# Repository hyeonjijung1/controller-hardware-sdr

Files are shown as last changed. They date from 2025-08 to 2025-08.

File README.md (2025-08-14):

# Subsystem C: SDR Controller Hardware  
_Led a 3-person team and delivered the Technical Review Presentation as Team Lead_

> **TL;DR:**  
> Modular SDR controller featuring custom 2-layer PCB, AVR firmware, and Si5351A frequency generation. Achieves ±1 kHz LO accuracy and 0.5° I/Q phase error—fully validated with oscilloscope and logic analyzer. Built, debugged, and documented from schematic to firmware to hardware bring-up.

**Technologies:**  Altium Designer · PCB Design · Embedded C (AVR) · ATmega324PB · Si5351A (I²C) · UART (CAT Protocol) · I²C LCD Interface · Bash & Python Scripting · Oscilloscope Validation · Git






A high-performance hardware controller built for **Software-Defined Radio (SDR)** systems, integrating **Local Oscillator (LO) generation**, **TX/RX control**, and a **user interface** to support modular, high-accuracy signal processing.

| 3D PCB Render | Assembled PCB |
|:---:|:---:|
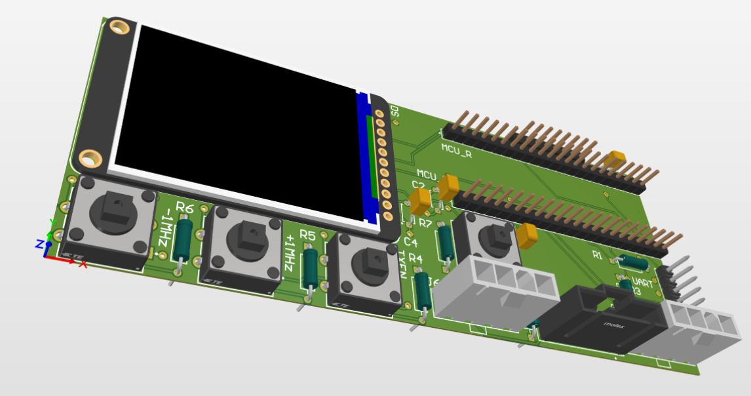
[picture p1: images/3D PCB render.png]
3D PCB Render
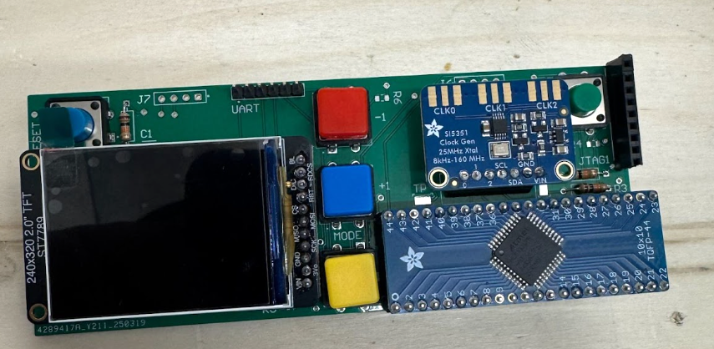
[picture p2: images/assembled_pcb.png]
Assembled PCB
|  |  |

<p align="center"><b>Figure:</b> 3D PCB render (left) and fully assembled SDR controller board (right).</p>

---
## Table of Contents

- [Project Summary](#project-summary)
- [Key Design Decisions](#key-design-decisions) 
- [Key Contributions & Impact](#key-contributions--impact)  
- [Getting Started](#getting-started)
- [Repo Structure](#repo-structure) 
- [Architecture](#architecture)  
- [PCB Design & Schematics](#pcb-design--schematics)
- [Challenges & Lessons Learned](#challenges--lessons-learned)
- [Validation & Test Results](#validation--test-results)
- [How to Replicate / Order PCB](#how-to-replicate--order-pcb)
- [Supporting Materials](#supporting-materials)  
- [What We Learned](#what-we-learned)  
- [Contact & Contributors](#contact--contributors)

---

## Project Summary

This repository contains the design and firmware for **Subsystem C** of a larger SDR transceiver. It handles:

- Generating a stable, precision **10 MHz LO** for quadrature mixers  
- **TX/RX gating** via an active-low enable signal  
- A **front-panel UI** (push-buttons + 16×2 I²C LCD) for frequency tuning and mode switching  
- **Automated hardware and firmware validation** using Bash and Python test scripts  
- Full compliance with the **Interface Control Document (ICD)**  

**Platform:** Custom 2-layer PCB (Altium Designer)  
**MCU:** ATmega324PB  
**Clock Generator:** Si5351A (I²C-programmable)  
**UI:** Push buttons + 16×2 character I²C LCD  
**Validation Tools:** Oscilloscope, Function Generator, Bash/Python automation scripts

---

## Key Design Decisions

Our design focused on intuitive user experience, reliable performance, and seamless integration with modular SDR systems.

- **Intuitive User Interface:**  
  Implemented three tactile push-buttons and a 16×2 I²C LCD on the front panel, enabling all key SDR controls—frequency tuning, TX/RX switching, and mode selection—without needing a PC or serial commands. This focus on usability makes the controller accessible to both technical and non-technical users.

- **Compact, Modular PCB Layout:**  
  Designed as a 128 × 51 mm daughtercard to fit within the overall SDR enclosure, supporting easy integration and replacement.

- **RF/Digital Trace Isolation:**  
  Separated RF signal paths from digital control sections to reduce noise and ensure clean LO generation.

- **Component Selection for Robustness:**  
  Chose the ATmega324PB microcontroller for ample I/O and the Si5351A for stable, programmable LO generation.

- **Testability and Validation:**  
  Included accessible test points and supported automated validation with Python/Bash scripts and oscilloscope measurements.

---
  
## Key Contributions & Impact

- **±1 kHz LO stability** (0.01% error) and **90° I/Q phase accuracy** under lab conditions  
- **50% faster** bring-up cycles using automated Python/bash test scripts  
- Designed & PCB-routed a **compact 128 × 51 mm** daughtercard, isolating RF traces from digital noise  
- Authored the **Technical Design Document**, detailing architecture, component trade-offs, and test plans  
- Programmed embedded C for **Si5351A (I²C)**, **UART (CAT protocol)**, and **LCD control**  
- **Led a 3-member team** end-to-end: schematic → PCB → firmware → integration  
- **Presented** the M2 Technical Review, covering timing closure, signal integrity, and ICD alignment  

---

## Getting Started

```bash
# Clone the Subsystem C repo
git clone https://github.com/hyeonjijung1/controller-hardware-sdr
cd controller-hardware-sdr

# Build firmware
make all

# Flash the ATmega324PB (via AVRDUDE or your preferred tool)
make flash
```
Once programmed, power the mainboard at 12 VDC, attach your UI module to J7/J8, and observe the LCD. Use the push-buttons to tune frequency and toggle TX/RX.

---

## 📁 Repo Structure

```bash
.
├── docs/                     # Project documents & design slides
│   ├── ECE295_Team4C_Technical_Design_Doc.pdf
│   ├── M2_design_review_slides.pdf
│   └── Team4C_OP2_Slides.pdf
├── firmware/                 # Embedded C source & build files
│   ├── include/              # Header files
│   │   ├── Si5351.h
│   │   └── twi.h
│   ├── src/                  # Source files
│   │   ├── main.c
│   │   ├── Si5351.c
│   │   └── twi.c
│   └── Makefile
├── hardware/                 # Altium project files
│   ├── Controller_Hardware_SDR_sch.SchDoc
│   └── Controller_Hardware_SDR.PcbDoc
├── images/                   # Visuals for documentation
│   ├── 3D PCB render.png
│   ├── assembled_pcb.png
│   └── Output LO waveforms demonstrating correct phase and amplitude.png
├── scripts/                  # Test & automation scripts
│   ├── cat_test.py
│   ├── lo_auto_validation.py
│   └── test_lo_accuracy.sh
├── LICENSE
└── README.md

```

---

## Architecture

Block Diagram
*Figure 1. Subsystem C SDR Block Diagram.*

---

## PCB Design & Schematics 

### PCB Design 

| 3D PCB Render | Top View | Bottom View |
|:---:|:---:|:---:|
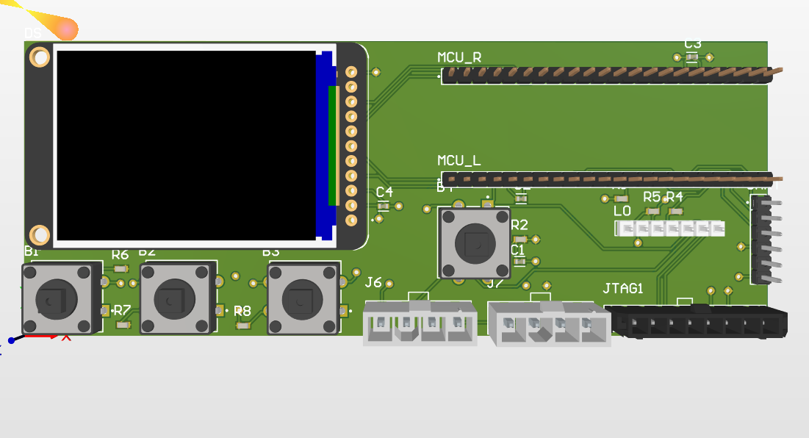
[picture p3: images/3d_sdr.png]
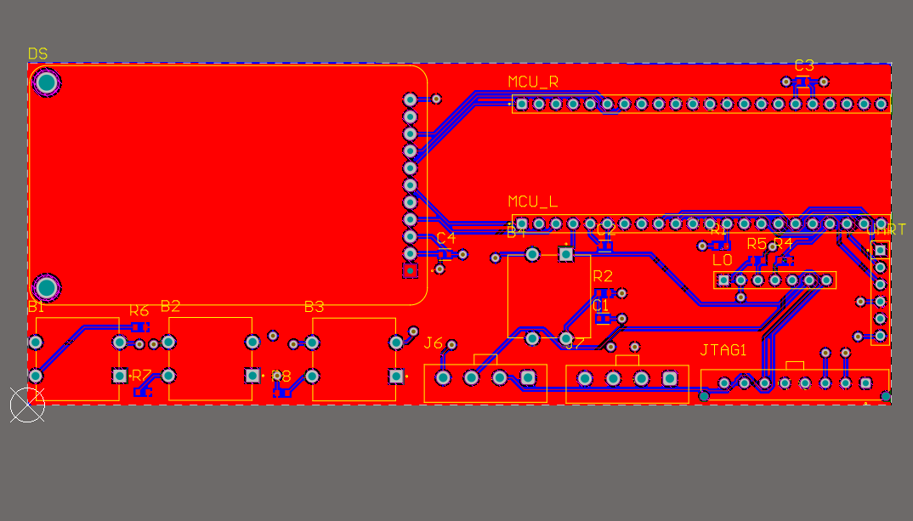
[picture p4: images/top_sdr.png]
PCB Top
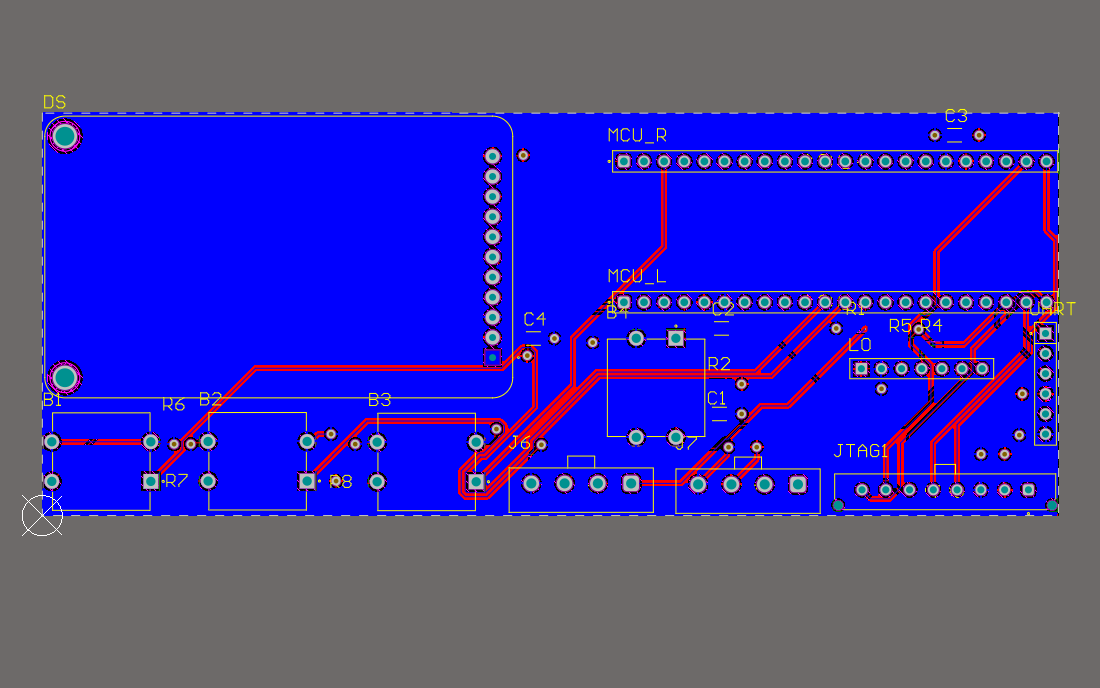
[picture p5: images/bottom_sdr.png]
PCB Bottom
|  |  |  |

<p align="center"><b>Figure:</b> 3D render, top, and bottom views of the SDR controller PCB (Altium Designer).</p>

### Schematics 

| Original Schematic | Final Schematic |
|:---:|:---:|
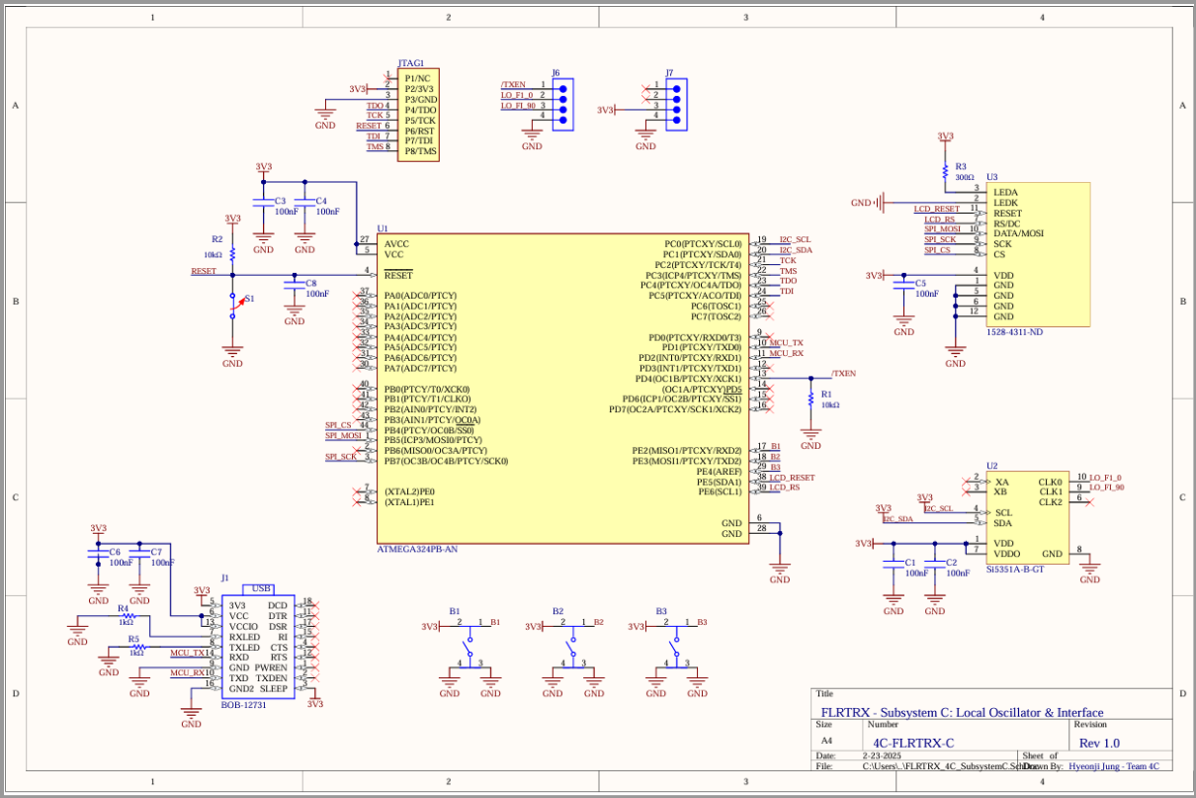
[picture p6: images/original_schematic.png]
Original Schematic
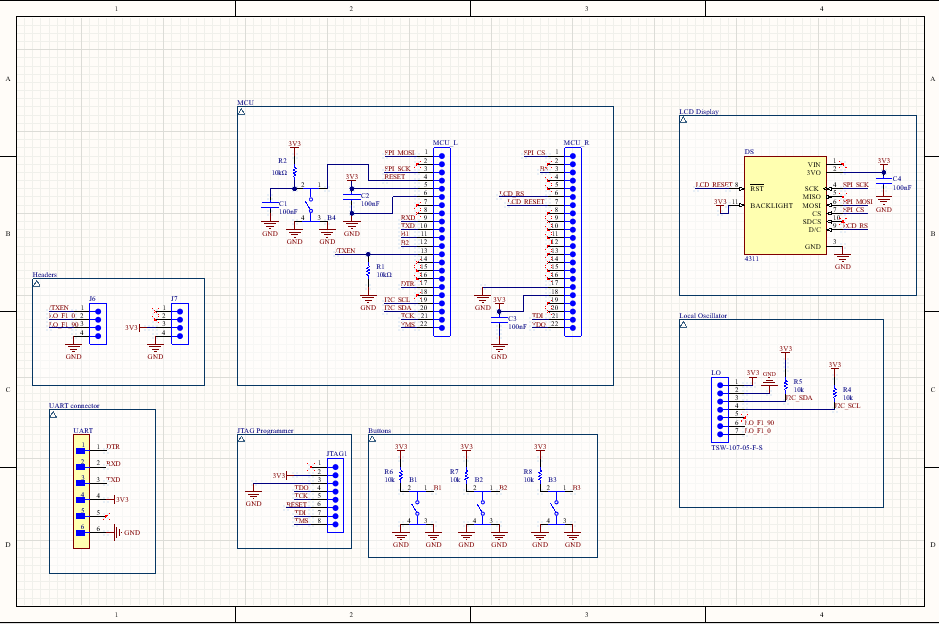
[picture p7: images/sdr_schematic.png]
schematic
|  |  |
<p align="center"><b>Figure:</b> Schematic in first iteration (left) and finalized Altium Schematic (right).</p>

---
## Challenges & Lessons Learned

Real hardware design is never plug-and-play—here’s what we faced and how we solved it:

- **Assembly Sequence Error:**  
  Our initial assembly failed because we soldered through-hole components before the surface-mount parts, preventing reflow soldering. We corrected this by assembling surface-mount components first on our next build.

- **Microcontroller Orientation Mistake:**  
  The ATmega324PB was mounted in the wrong orientation, misaligning the pinout and breaking the logic chain. To recover, we used jumper wires with male-to-female headers to manually connect the MCU to the correct pads—an inelegant but functional patch.

| Wrong MCU Orientation (Design/Assembly) | Corrected with Jumper Wires |
|:---:|:---:|
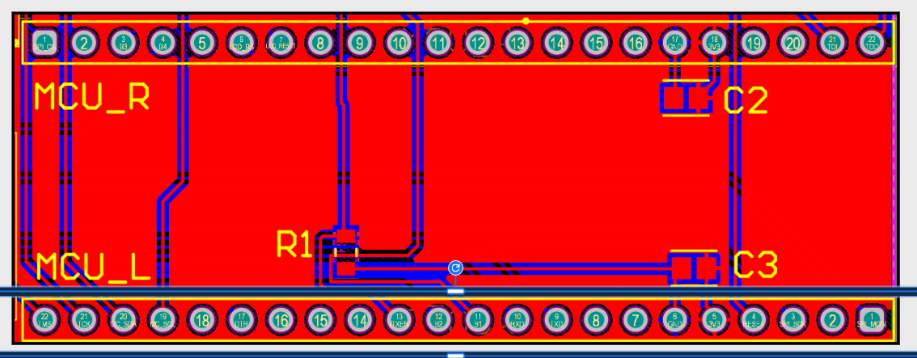
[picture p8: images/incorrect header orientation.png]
MCU wrong orientation in Altium PCB
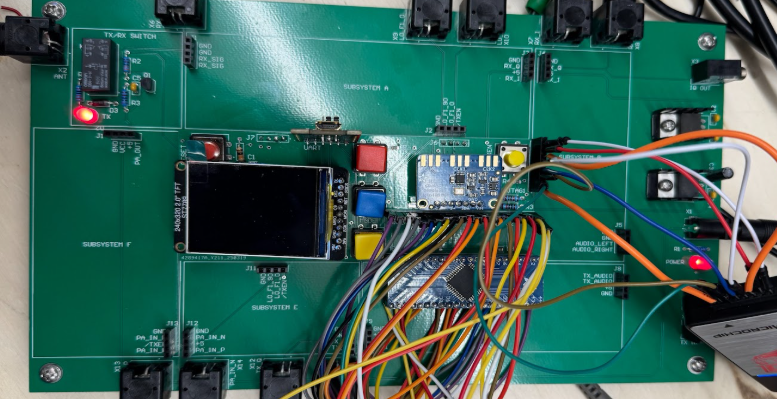
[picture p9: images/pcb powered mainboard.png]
Jumper wires patching MCU orientation
|  |  |
| <sub><b>Figure:</b> PCB as assembled with incorrect MCU orientation;logic chain broken.</sub> | <sub><b>Figure:</b> Functional patch using jumper wires to restore connections after the assembly error.</sub> |

- **Button Instability:**  
  Some push-buttons failed on the PCB despite working on breadboard. The reset button, a different type, worked reliably, pointing to hardware quality issues.

- **TXEN Signal Glitch:**  
  The TXEN (Transmit Enable) signal toggled incorrectly due to a debounce/logic error in firmware. Despite several software fixes, the issue persisted and requires further debugging.

- **UART Communication Issues:**  
  Serial comms established, but the MCU sometimes sent incorrect/blank responses. Switching to interrupt-based UART caused repeated interrupts, locking the radio in computer-control mode—an unresolved but valuable learning experience.

**Key Takeaway:**  
Every challenge forced us to dig deeper, learn new debugging skills, and improvise fixes to keep the project moving forward; real hardware design in a nutshell.

---

## Validation & Test Results

| Test | Target / Spec | Result / Measured | Status |
|---|---|---|---|
| LO Frequency Accuracy | ±1 kHz @ 10 MHz | ±1 kHz (oscilloscope) | ✔️ |
| I/Q Phase Error | <1° | ~0.5° (measured) | ✔️ |
| TX/RX Switching Time | <2 ms | ~1 ms (logic analyzer) | ✔️ |

Output LO Waveform (10 MHz, Oscilloscope)
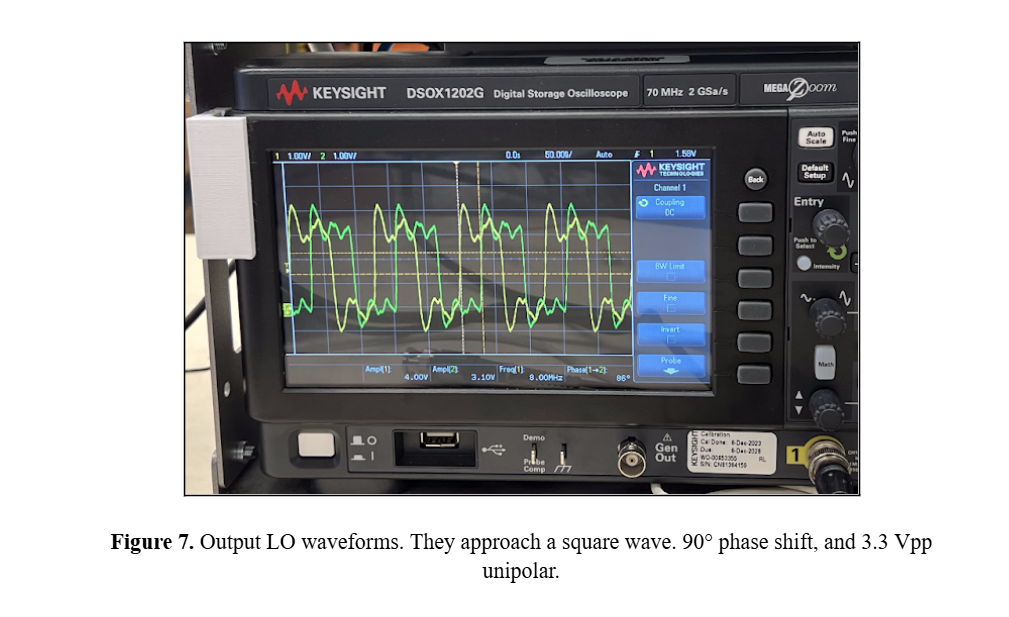
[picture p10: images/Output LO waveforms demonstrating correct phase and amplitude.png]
output


<p align="center"><b>Figure:</b> Measured LO output at 10 MHz on oscilloscope. This demonstrates stable, low-jitter signal generation by Si5351A module. Test performed post-assembly.</p>

---

## How to Replicate / Order PCB

Interested in building your own Subsystem C SDR Controller? Here’s how:

1. **Clone the repository:**
   ```bash
   git clone https://github.com/hyeonjijung1/controller-hardware-sdr
    ```
2. **Download hardware design files:**  
- Altium schematic (`.SchDoc`) and PCB (`.PcbDoc`) files are in `/hardware`
- BOM/parts list can be found in the schematic

3. **Order & fabricate PCB:**  
- Open PCB in Altium Designer, export Gerber & drill files (`File > Fabrication Outputs > Gerber Files`)
- Upload Gerbers to a PCB fab (e.g., JLCPCB, PCBWay)
- Order components from DigiKey, Mouser, or LCSC

4. **Assemble the board:**  
- Solder **surface-mount** components first (reflow oven recommended), then through-hole parts
- Double-check microcontroller orientation (refer to schematic/silkscreen)

5. **Build & flash firmware:**  
- In `/firmware`, run `make all`
- Flash ATmega324PB using AVRDUDE or compatible programmer

6. **Test your build:**  
- Power with 12 VDC, connect LCD/UI
- Validate LO output on oscilloscope
- Test push-buttons, TX/RX switching, and serial CAT protocol

> *Tip: Hardware bring-up is never plug-and-play. If you run into issues, check the “Challenges” section above for inspiration!*

---

## Supporting Materials

- [Technical Design Document (PDF)](https://drive.google.com/file/d/1lXBYHzfA1NsGeK7o8hkGUYrSS2hV9RxU/view?usp=sharing)
- [M2 Technical Presentation Slides (PDF)](https://drive.google.com/drive/u/0/folders/1bPhXOaGDvTHJFP-_4Y7tE-j0aOfVJy6w)
- [OP1 General Audience Slides (PDF)](https://drive.google.com/drive/u/0/folders/1bPhXOaGDvTHJFP-_4Y7tE-j0aOfVJy6w)
- [OP2 General Audience Slides (PDF)](https://drive.google.com/drive/u/0/folders/1bPhXOaGDvTHJFP-_4Y7tE-j0aOfVJy6w)

---

## What We Learned

- Orchestrating multi-protocol I/O (I²C + UART + GPIO) on a constrained MCU  
- Achieving tight frequency tolerance within noise and thermal drift margins  
- ICD-driven design: enforcing electrical & mechanical interface specs across teams  
- PCB routing strategies to isolate analog/RF from noisy digital sections  
- Leadership: coordinating cross-functional goals, documentation, and presentations under deadline  

---
 
## Contact & Contributors




**Diana(Hyeonji) Jung**  
Team Lead & Presenter  

**Contributors:**  
- Laura Marinescu  
- Chizaram Amobi-Oleka

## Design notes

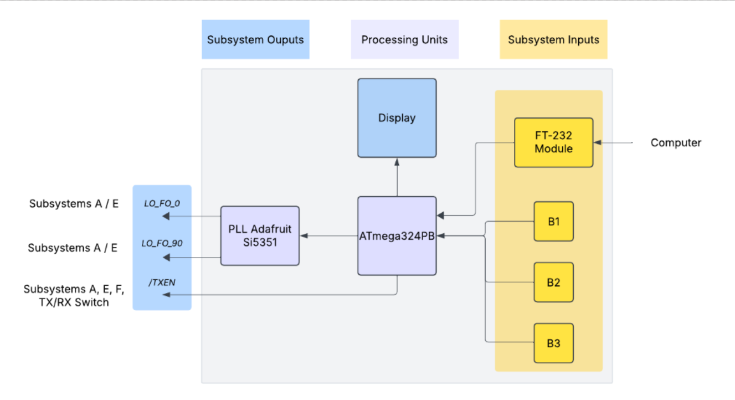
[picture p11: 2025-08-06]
images/block_diagram_sdr.png

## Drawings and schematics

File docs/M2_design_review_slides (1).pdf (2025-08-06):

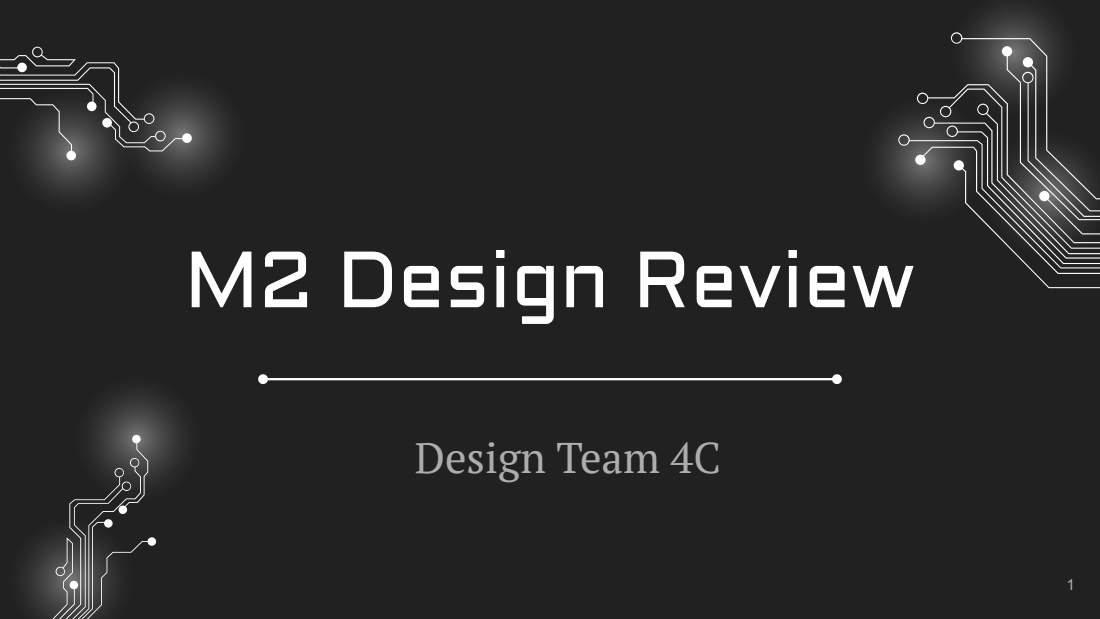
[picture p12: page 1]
M2 Design Review; Design Team 4C

# Table of contents

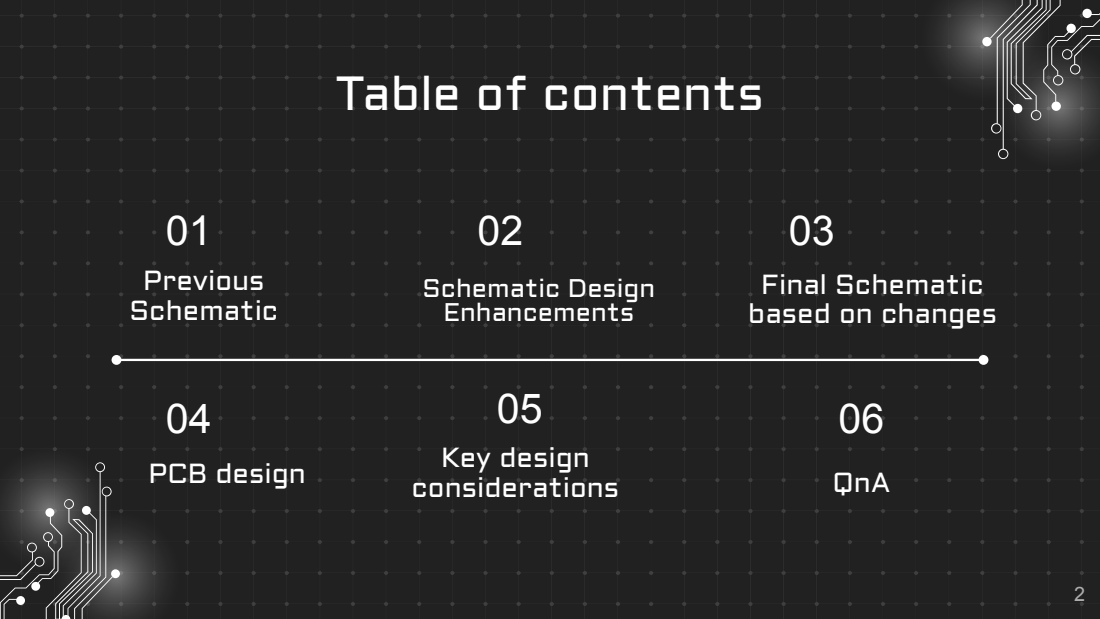
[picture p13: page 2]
Previous Schematic; Schematic Design Enhancements; PCB design; Key design; considerations; QnA

Final Schematic
based on changes

# Previous Schematic for M1

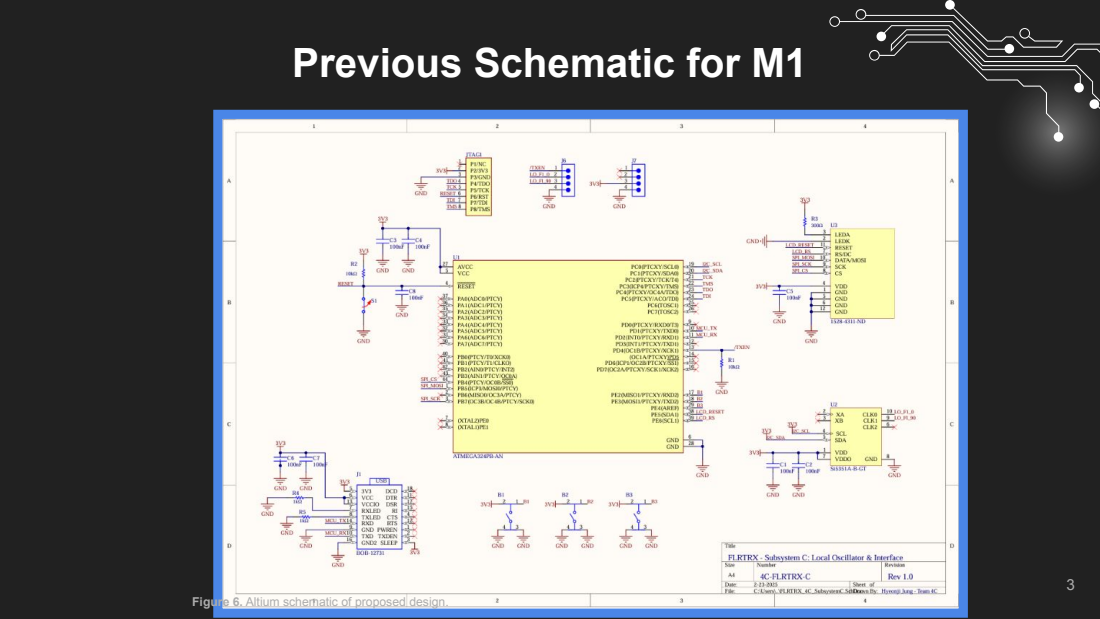
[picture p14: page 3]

Figure 6. Altium schematic of proposed design.

# Change 1. Included Boxes for Clarity

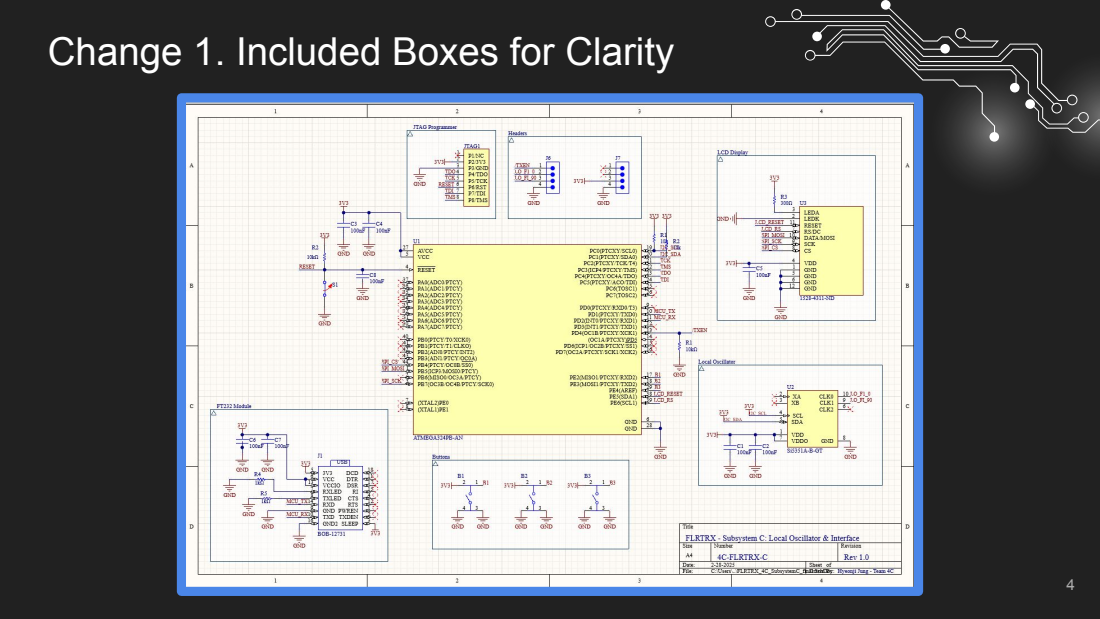
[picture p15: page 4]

Change 2. Reset switch into buttons,

# Surface mount → Through Hole components

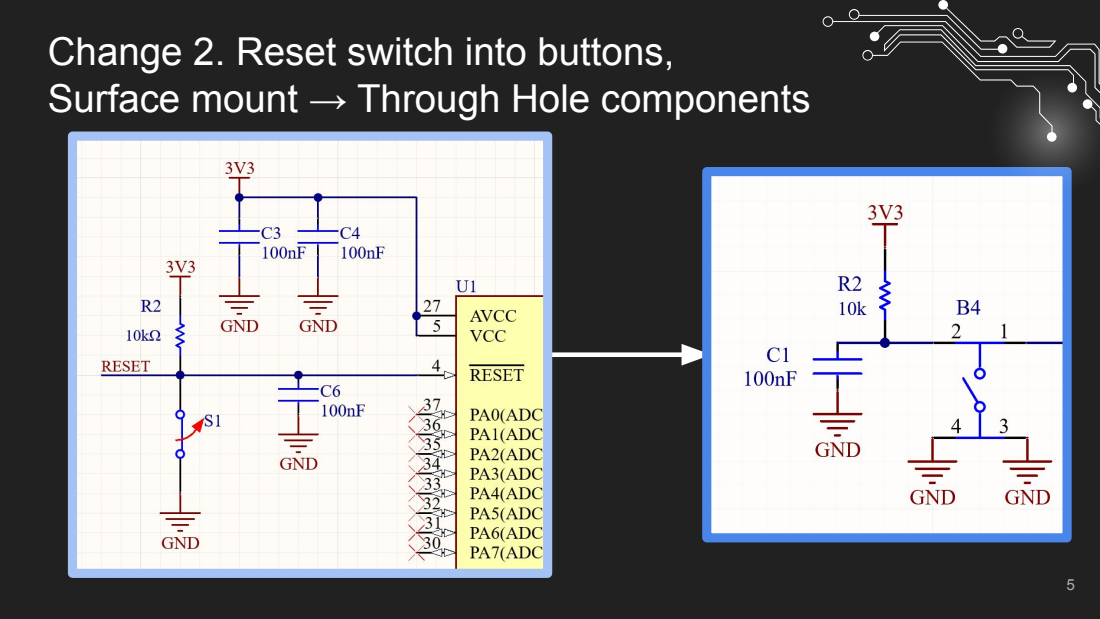
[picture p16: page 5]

# Change 3. Included Pull-up Resistors (buttons, I2C lines)

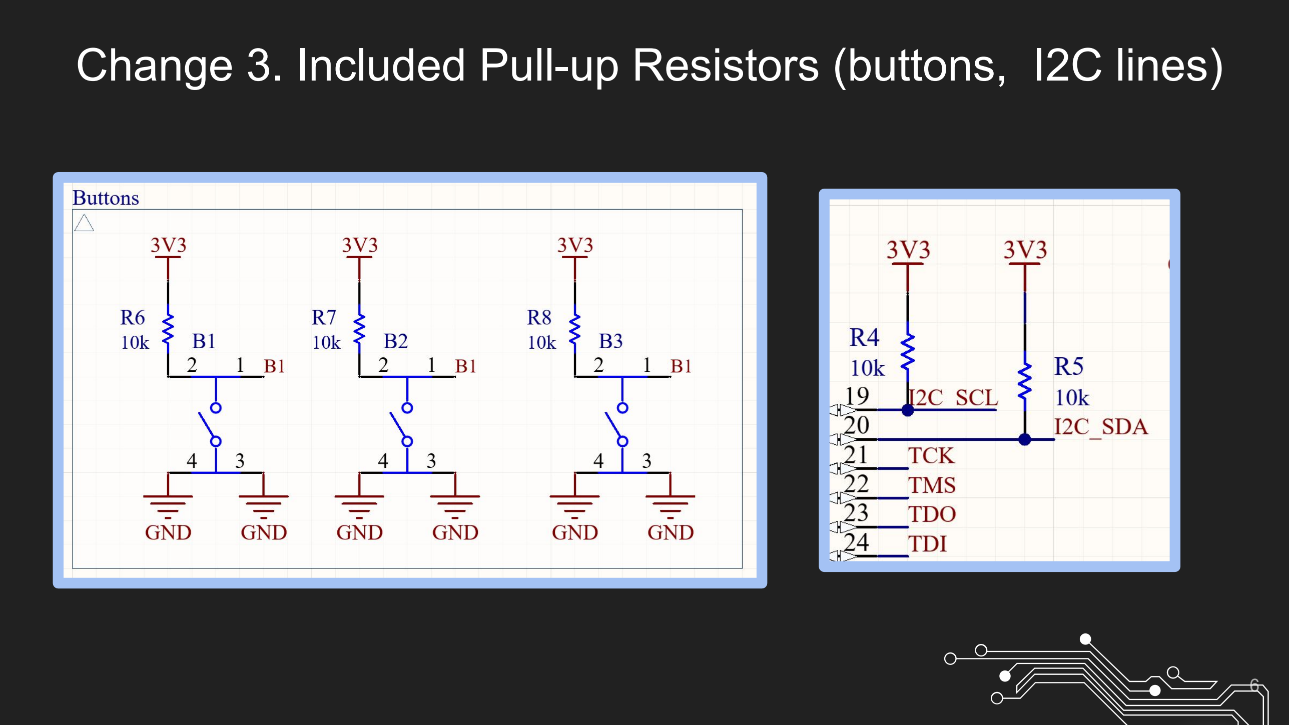
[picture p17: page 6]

# Change 4. LO module into headers

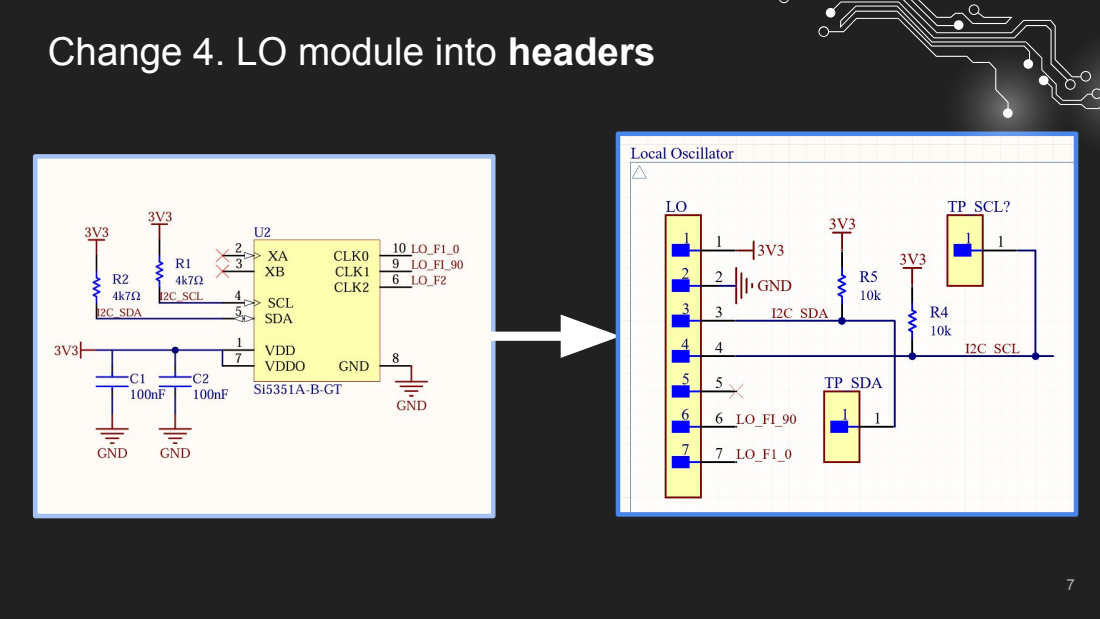
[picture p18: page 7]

# Change 5. FT232 module into headers

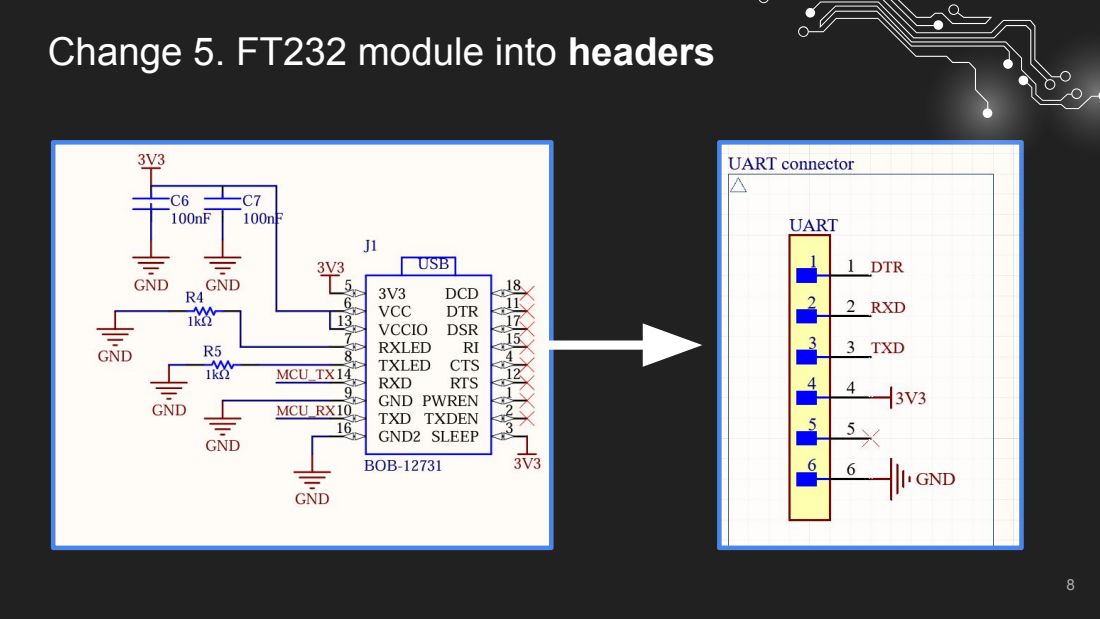
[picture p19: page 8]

# Change 6. Change MCU into 2 22 pin female headers

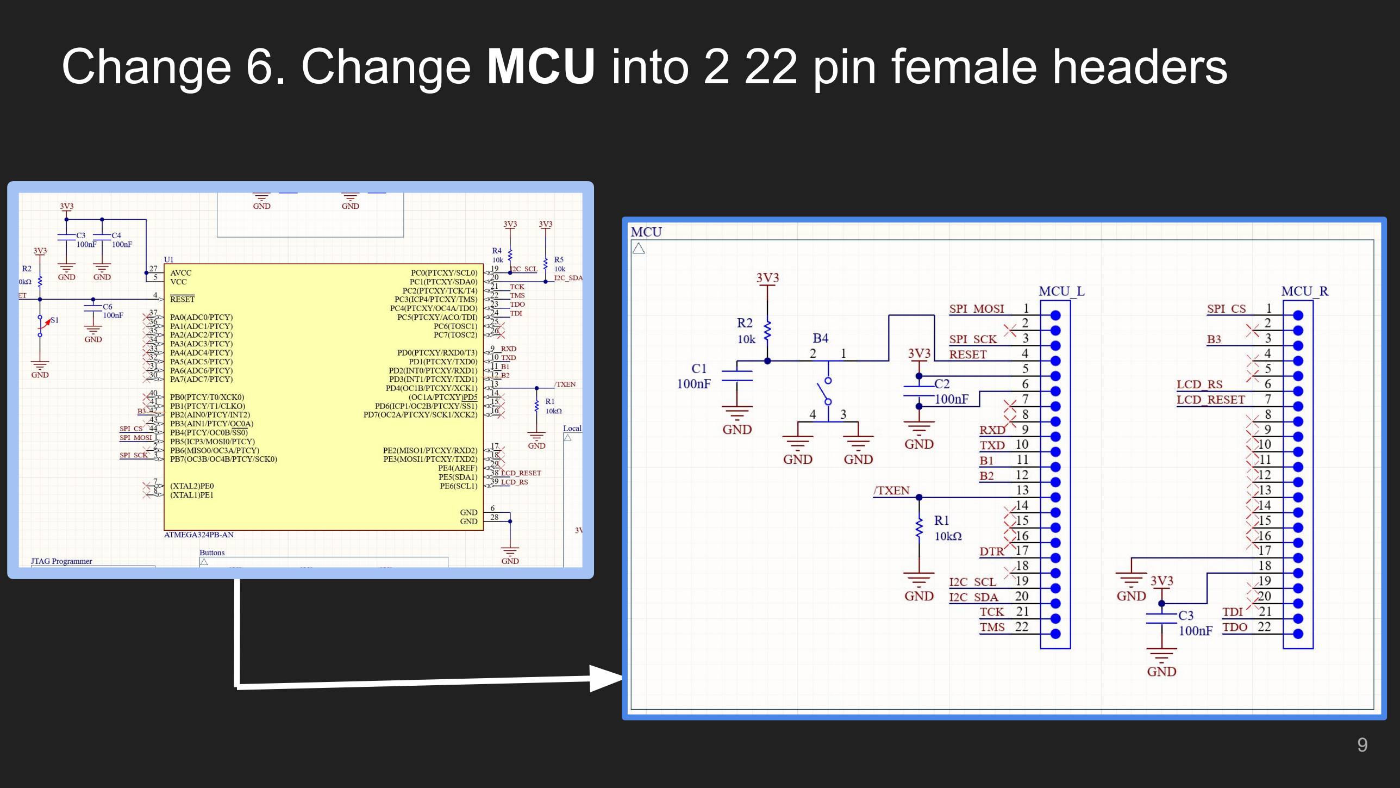
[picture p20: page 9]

# Change 7. Add Testing Points for I2C lines

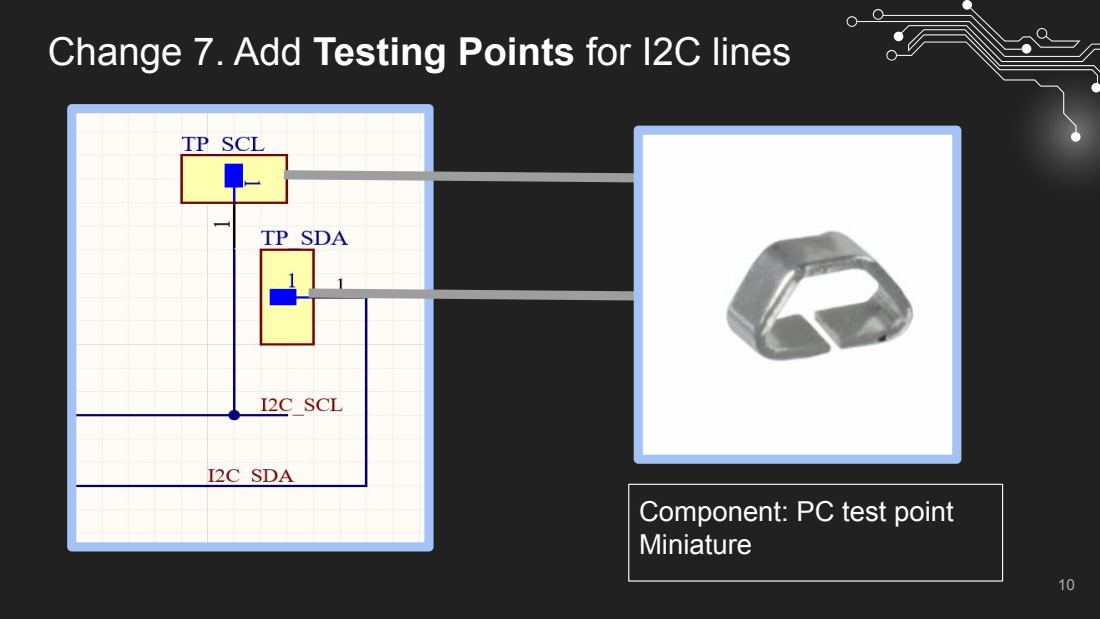
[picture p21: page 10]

Component: PC test point
Miniature

# Final Schematic based on Changes from M1

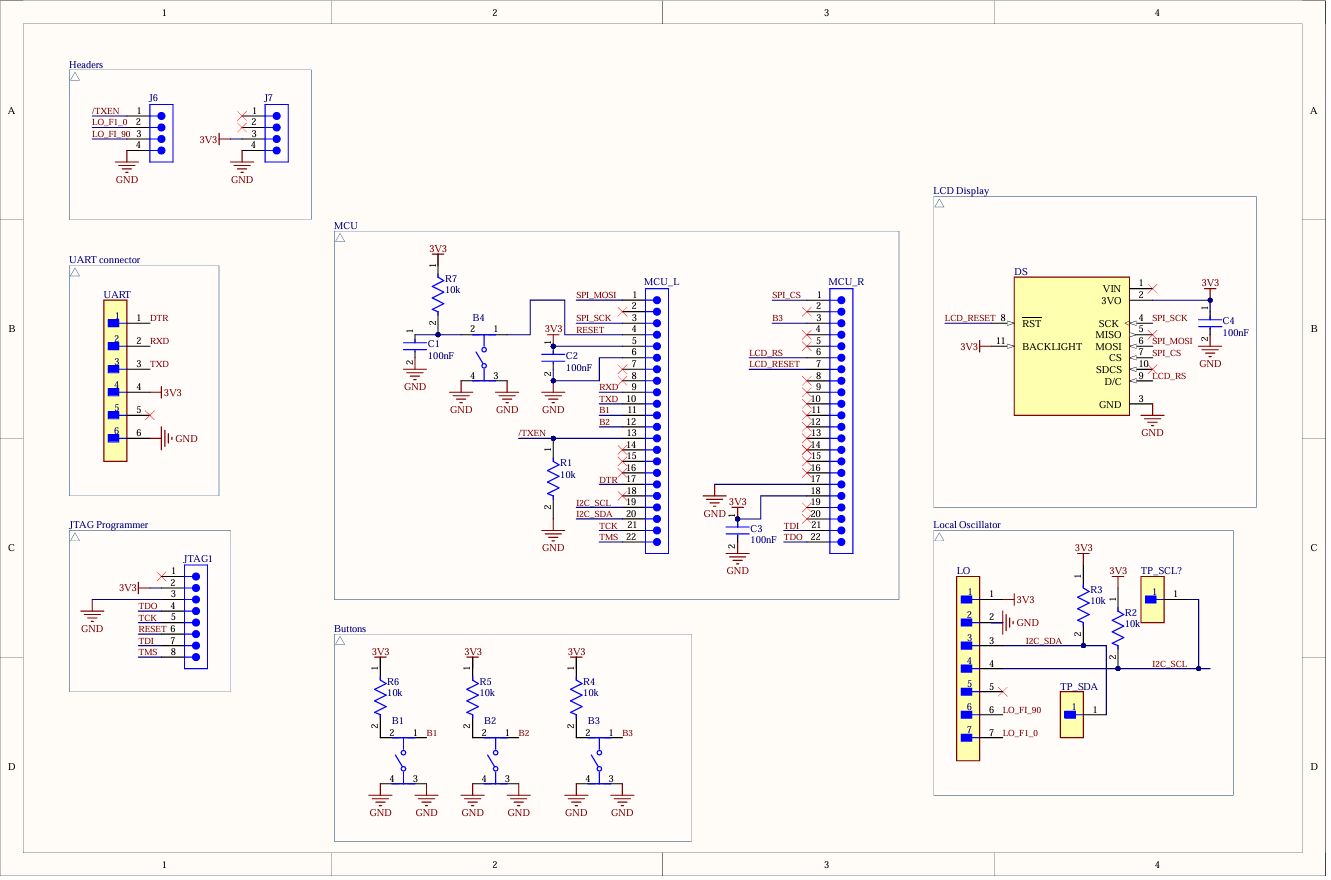
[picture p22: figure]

# PCB Iteration Process

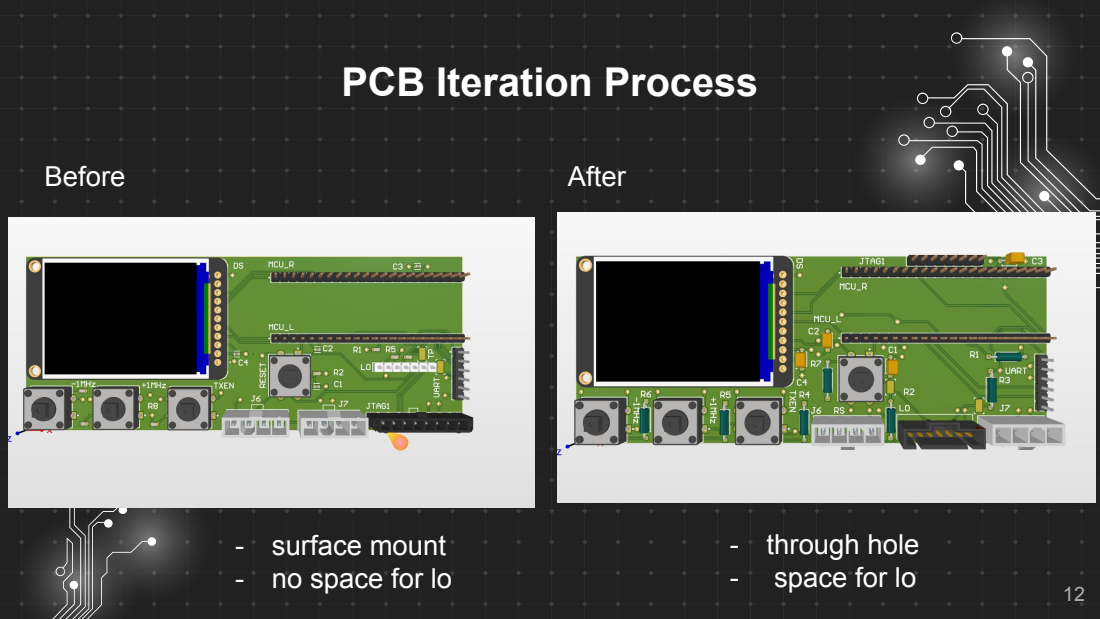
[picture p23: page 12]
Before; After

- surface mount
- no space for lo

- through hole
- space for lo

# PCB Iteration Process

Before; After

less congestion in lines
to minimize EMI

# Components of Finalized PCB

Component; ATmega324PB; Adafruit Si5351A; FT232R Module; Adafruit 4311 LCD Display; Adafruit 1010 Buttons

# UI portion of PCB


# PCB before polygon pours


# Top layer PCB

Polygon Poured 3.3V

# Bottom layer PCB

Polygon Poured GND

# 3D view of Bottom layer PCB


# Key PCB Design Considerations


# - JTAG & UART at PCB edge for access - LO near MCU for connectivity - Header pins for MCU (PCB ↔ Breadboard) - Vias for signal integrity - Polygon pours (3.3V & GND)

# Thank you for Listening!

# Additional information including are provided in the onenote

ECE295- Design Team 4

QnA

## References

[1] S. V. Hum, "Flexible Radio Transceiver (FLRTRX) Interface Control Document," ECE295: Hardware Design and Communication, v4.0. [Online]. Available: https://www.ab4oj.com/sdr/sdr_handbook.pdf. [Accessed: Jan. 27, 2025].
[2] Microchip Technology Inc., "ATmega164P/324P/644P data sheet," *Microchip Technology*, 40002071A, 2014. [Online]. Available: https://ww1.microchip.com/downloads/aemDocuments/documents/OTH/ProductDocuments/DataSheets/ATmega164P-324P-644P-D ata-Sheet-40002071A.pdf. (https://ww1.microchip.com/downloads/aemDocuments/documents/OTH/ProductDocuments/DataSheets/ATmega164P-324P-644P-Data-Sheet-40002071A.pdf) [Accessed: Jan 30, 2025].

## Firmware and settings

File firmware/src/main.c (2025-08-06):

/*
 * File:   main.c
 * Authors: ECE295 Design Team 4C: Laura Marinescu, Hyeonji Jung, Chizaram Amobi-Oleka
 *
 * Created on March 1, 2025, 2:50 PM
 *
 */

 #include <avr/io.h>
 #include <util/delay.h>
 #include <avr/interrupt.h>
 #include <string.h>
 #include <stdio.h>
 #include <stdlib.h>
 
 #include "Si5351.h"
 #include "twi.h"
 
 /* GLOBAL VARIABLES AND DEFINES */
 #define PLL_FREQUENCY 800000000UL            // VCO frequency = 800 MHz
 #define INITIAL_OUTPUT_FREQUENCY 10000000UL    // 10 MHz default
 #define BAUD 9600
 #define MYUBRR (F_CPU/16/(BAUD-1))
 
 volatile uint32_t output_frequency = INITIAL_OUTPUT_FREQUENCY;
 volatile uint32_t step_size = 1000000UL;  // Default step = 1 MHz
 volatile uint8_t precision_mode = 0;      // 0: 1MHz, 1: 100kHz, etc.
 volatile int txen = 0;                    // TX state: 0 = RX, 1 = TX
 
 // Additional states for CAT commands:
 volatile uint8_t ai_state = 0;   // For AI command
 volatile uint8_t st_state = 0;   // For ST command
 
 /* FUNCTION PROTOTYPES */
 void configure_si5351(uint32_t frequency);
 void incFreq(void);
 void decFreq(void);
 void toggle_txen(void);
 void change_step_size(void);
 
 void UART_init(unsigned int ubrr);
 void UART_transmit(unsigned char data);
 unsigned char UART_receive(void);
 
 /* CAT protocol functions */
 void comp_ctrl_mode(void);
 static void parseCATCommand(char *cmd);
 static void sendCATResponse(const char *resp);
 
 int main(void) {  
     /* Initialize I2C, Si5351, etc. */
     twi_init();
     si5351_init();
     reset_pll();
     configure_si5351(output_frequency);
     
     /* Initialize UART */
     UART_init(MYUBRR);
     
     /* Initialize pins */
     // Button input pins: PD2, PD3, PD5, PB2
     DDRD &= ~(1 << DDD2);
     DDRD &= ~(1 << DDD3);
     DDRD &= ~(1 << DDD5);
     DDRB &= ~(1 << DDB2);

     // enable pull up resistors on input pins
     PORTD |= (1 << PD2) | (1 << PD3) | (1 << PD5);
     PORTB |= (1 << PB2);
     
     // TXEN output on PD4, start disabled (TX off)
     DDRD |= (1 << DDD4);
     PORTD &= ~(1 << PD4);
     
     // USB-to-UART pins:
     // DTR input on PE2, RXD (PD1) as input, TXD (PD0) as output
     DDRE &= ~(1 << DDE2);
     DDRD &= ~(1 << DDD1);
     DDRD |= (1 << DDD0);
             
     volatile uint8_t b1_value, b2_value, b3_value, b4_value;
     volatile uint8_t dtr_val;
  
     while (1) {
         b1_value = (PIND & (1 << PIND2)) >> PIND2;
         b2_value = (PIND & (1 << PIND3)) >> PIND3;
         b3_value = (PINB & (1 << PINB2)) >> PINB2; // pin B2 is the input of B3 which controls state of TXEN
         b4_value = (PIND & (1 << PIND5)) >> PIND5;
          
         // Check DTR (used to enter CAT mode)
         dtr_val = (PINE & (1 << PINE2)) >> PINE2;
         if (dtr_val) {
             comp_ctrl_mode();
         }
          
         // Button-driven manual controls
         if (b1_value) incFreq();
         if (b2_value) decFreq();
         if (!b3_value) toggle_txen();   // ADDED ! CONDITION. When button is pressed, we should toggle TXEN.
         if (b4_value) change_step_size();
     }
 }
  
 /* Configure Si5351 Frequency */
 void configure_si5351(uint32_t frequency) {
     uint32_t divider = PLL_FREQUENCY / frequency;
     setup_PLL(SI5351_PLL_A, PLL_FREQUENCY / SI5351_XTAL_FREQ, 0, 1);
     setup_clock(SI5351_PLL_A, SI5351_PORT0, divider, 0, 1);
     setup_clock(SI5351_PLL_A, SI5351_PORT1, divider, 0, 1);        // ADDED LINE FOR PORT1
     set_phase(90);
     enable_clocks(true);
 }
  
 /* Increase Frequency */
 void incFreq(void) {
     if (output_frequency + step_size <= 16000000UL) {
         output_frequency += step_size;
         configure_si5351(output_frequency);
     }
 }
  
 /* Decrease Frequency */
 void decFreq(void) {
     if (output_frequency - step_size >= 8000000UL) {
         output_frequency -= step_size;
         configure_si5351(output_frequency);
     }
 }
  
 /* Change Frequency Step Size */
 void change_step_size(void) {
     precision_mode = (precision_mode + 1) % 4;
     switch (precision_mode) {
         case 0: step_size = 1000000UL; break;  // 1 MHz
         case 1: step_size = 100000UL;  break;   // 100 kHz
         case 2: step_size = 10000UL;   break;   // 10 kHz
         case 3: step_size = 1000UL;    break;   // 1 kHz
     }
 }
  
 /* Toggle TX/RX state via TXEN pin */
 void toggle_txen(void) {
     txen ^= 1;
     if (txen) {
         PORTD |= (1 << PD4);   // TX enabled
     } else {
         PORTD &= ~(1 << PD4);  // TX disabled
     }
 }
  
 /* UART Initialization */
 void UART_init(unsigned int ubrr) {
     UBRR0H = (unsigned char)(ubrr >> 8);
     UBRR0L = (unsigned char)ubrr;
     
     // Enable receiver and transmitter.
     UCSR0B = (1 << RXEN) | (1 << TXEN);
     
     // 8 data bits, 1 stop bit, no parity.
     // Set UCSZ1 and UCSZ0 bits to get 8-bit character size.
     UCSR0C = (1 << UCSZ1) | (1 << UCSZ0);
 }
  
 /* UART Transmit */
 void UART_transmit(unsigned char data) {
     while (!(UCSR0A & (1 << UDRE0))) { }
     UDR0 = data;
 }
  
 /* UART Receive */
 unsigned char UART_receive(void) {
     while (!(UCSR0A & (1 << RXC0))) { }
     return UDR0;
 }
  
 //
 // CAT Protocol Handling
 //
  
 /**
  * Reads characters until a semicolon is received (end of command)
  * and then calls parseCATCommand() to process the command.
  */
 void comp_ctrl_mode(void) {
     char rx_buffer[32] = {0};
     uint8_t i = 0;
      
     while ((PINE & (1 << PINE2)) >> PINE2) { // While DTR is active
         char received = UART_receive();
         if (received == ';') {
             rx_buffer[i] = '\0';
             parseCATCommand(rx_buffer);
             i = 0;
             memset(rx_buffer, 0, sizeof(rx_buffer));
         } else {
             if (i < (sizeof(rx_buffer) - 1)) {
                 rx_buffer[i++] = received;
             }
         }
     }
 }
  
 /**
  * Parses CAT commands.
  * Commands supported:
  *   TX – Transmit/Receive state
  *   FA – Frequency set/query (9-digit frequency in Hz)
  *   AI – Additional command state (0 or 1)
  *   ID – Returns static ID ("ID0650;")
  *   MD – Mode query; returns "MD0C;"
  *   SH – Returns "SH0000;"
  *   NA – Returns "NA00;"
  *   IF – Returns status string ("IF001%09lu+000000C00000;")
  *   ST – Secondary state command
  */
 static void parseCATCommand(char *cmd) {
     // TX Command
     if (strncmp(cmd, "TX", 2) == 0) {
         if (cmd[2] == '\0') { // Query
             char resp[8];
             sprintf(resp, "TX%d;", txen);
             sendCATResponse(resp);
         } else {
             if (cmd[2] == '0') {
                 if (txen != 0) { toggle_txen(); }
             } else if (cmd[2] == '1') {
                 if (txen != 1) { toggle_txen(); }
             }
         }
     }
     // FA Command (Frequency)
     else if (strncmp(cmd, "FA", 2) == 0) {
         if (cmd[2] == '\0') { // Query frequency
             char resp[16];
             sprintf(resp, "FA%09lu;", (unsigned long)output_frequency);
             sendCATResponse(resp);
         } else { // Set frequency
             uint32_t newFreq = strtoul(&cmd[2], NULL, 10);
             if (newFreq >= 8000000UL && newFreq <= 16000000UL) {
                 output_frequency = newFreq;
                 configure_si5351(output_frequency);
             }
         }
     }
     // AI Command
     else if (strncmp(cmd, "AI", 2) == 0) {
         if (cmd[2] == '\0') { // Query
             char resp[8];
             sprintf(resp, "AI%d;", ai_state);
             sendCATResponse(resp);
         } else { // Set
             if (cmd[2] == '0' || cmd[2] == '1') {
                 ai_state = cmd[2] - '0';
             }
         }
     }
     // ID Command
     else if (strncmp(cmd, "ID", 2) == 0) {
         sendCATResponse("ID0650;");
     }
     // MD Command
     else if (strncmp(cmd, "MD", 2) == 0) {
         if (cmd[2] == '0') {
             sendCATResponse("MD0C;");
         }
     }
     // SH Command
     else if (strncmp(cmd, "SH", 2) == 0) {
         sendCATResponse("SH0000;");
     }
     // NA Command
     else if (strncmp(cmd, "NA", 2) == 0) {
         sendCATResponse("NA00;");
     }
     // IF Command
     else if (strncmp(cmd, "IF", 2) == 0) {
         char resp[32];
         sprintf(resp, "IF001%09lu+000000C00000;", (unsigned long)output_frequency);
         sendCATResponse(resp);
     }
     // ST Command
     else if (strncmp(cmd, "ST", 2) == 0) {
         if (cmd[2] == '\0') { // Query
             char resp[8];
             sprintf(resp, "ST%d;", st_state);
             sendCATResponse(resp);
         } else {
             if (cmd[2] == '0' || cmd[2] == '1') {
                 st_state = cmd[2] - '0';
             }
         }
     }
     // Unrecognized command: No response
 }
  

 static void sendCATResponse(const char *resp) {
     while (*resp) {
         UART_transmit(*resp++);
     }
 }
 

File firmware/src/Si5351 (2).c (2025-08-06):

#include "./Si5351.h"

static void write(byte addr, byte data);
static byte read(byte addr);
static void enableSpreadSpectrum(bool enabled);
static void write_bulk(byte addr, byte* data, int len);

uint32_t lastRdivValue[3];

/* 
 * write procedure for PLL device
 * works very similar to encoder procedure
 * refer to encoder procedure to see how it works
 *
 */

void write(byte addr, byte data)
{
    // TODO: FL2 fill this in with
    // start condition
    // write I2C address for si5351 (SI5351_ADDR constant)
    // write register address
    // write register data
    // stop condition
	
    twi_start(); 
    // Send Si5351 device address
    twi_MT_SLA_W(SI5351_ADDR);  
    // Send register address
    twi_MT_write(addr);   
    // Send data
    twi_MT_write(data);
    twi_stop();

}

/*
 * write procedure but multiple data points
 */

void write_bulk(byte addr, byte* data, int len)
{
    twi_start();
    twi_MT_SLA_W(SI5351_ADDR);
    twi_MT_write(addr);
    for(int i = 0; i < len; ++i)
        twi_MT_write(data[i]);

    twi_stop();
}

/*
 * set phase by writing 0 and mult (previously set to guarantee 90 deg)
 * to the two different clocks
 * 
 */

void set_phase(word mult) 
{
    mult &= 0b1111111;
    write(SI5351_REGISTER_165_CLK0_INITIAL_PHASE_OFFSET, 0);
    write(SI5351_REGISTER_166_CLK1_INITIAL_PHASE_OFFSET, mult);
    write(SI5351_REGISTER_177_PLL_RESET, (1 << 7) | (1 << 5));
}

/*
 * read procedure for PLL
 * very similar to encoder, see reference
 *
 */

byte read(byte addr)
{
    volatile byte ret;
    volatile byte ret_MT_write;
    volatile byte ret_SLA_R;
    twi_start();
    ret = twi_MT_SLA_W(SI5351_ADDR);
	if(ret != 0x18){
		return 0xFF;
	}
    ret_MT_write = twi_MT_write(addr);
	if(ret_MT_write != 0x28){
		return 0xFF;
	}
    twi_repeat_start();
    ret_SLA_R = twi_MR_SLA_R(SI5351_ADDR);	
	if(ret_SLA_R != 0x40){
		return 0xFF;
	}
    ret = twi_MR_read_NACK();
    twi_stop();
    return ret;
}

/*
 * Code to turn on/off spectrum feature. Not used in the project
 */
void enableSpreadSpectrum(bool enabled) {
    byte regval = read(SI5351_REGISTER_149_SPREAD_SPECTRUM_PARAMETERS);
    if(enabled) 
        regval |= 0x80;
    else 
        regval &= ~0x80;

    write(SI5351_REGISTER_149_SPREAD_SPECTRUM_PARAMETERS, regval);
}

/* 
 * Initialise the device in our project
 * Reset all the internal clocks 
 */ 
void si5351_init()
{
    for(int i = 0; i < 3; ++i) lastRdivValue[i] = 0;
    byte status = 0;
    /* wait for device to start */
    /*do {
	    //status = read(SI5351_REGISTER_0_DEVICE_STATUS);
	    status = read(SI5351_REGISTER_1_INTERRUPT_STATUS_STICKY);
		_delay_ms(1);
    } while (status >> 7 == 1);

*/
	
    write(SI5351_REGISTER_183_CRYSTAL_INTERNAL_LOAD_CAPACITANCE, 
        (SI5351_CRYSTAL_LOAD_10PF & SI5351_CRYSTAL_LOAD_MASK) | 0b00010010);

    write(SI5351_REGISTER_16_CLK0_CONTROL, 0x80); 
    write(SI5351_REGISTER_17_CLK1_CONTROL, 0x80); 
    write(SI5351_REGISTER_18_CLK2_CONTROL, 0x80);
    write(SI5351_REGISTER_19_CLK3_CONTROL, 0x80);
    write(SI5351_REGISTER_20_CLK4_CONTROL, 0x80);
    write(SI5351_REGISTER_21_CLK5_CONTROL, 0x80);
    write(SI5351_REGISTER_22_CLK6_CONTROL, 0x80);
    write(SI5351_REGISTER_23_CLK7_CONTROL, 0x80);

    write(16, 0x0c);
	write(17, 0x0c);
	write(18, 0x0c);
	write(19, 0x0c);
	write(20, 0x0c);
	write(21, 0x0c);
	write(22, 0x0c);
	write(23, 0x0c);

    enableSpreadSpectrum(false);  
}

/*
 * Turn off/on the clocks
 */

void enable_clocks(bool enabled)
{
    write(SI5351_REGISTER_3_OUTPUT_ENABLE_CONTROL, enabled ? 0x00 : 0xFF);
}

/*
 * Setup reference frequency (fvco) based on the XTAL crystal frequency (25MHz)
 * Code taken and slightly modified from adafruit si5351 library
 * 
 */

void setup_PLL(plldev_t pll, byte mult, uint32_t num, uint32_t denom)
{
    
    if( mult < 15 || mult > 90 ) return;    // multiple not supported
    if( (denom == 0) || (denom > 0xFFFFF) ) return;
    if( num > 0xFFFFF) return;

    uint32_t P1, P2, P3;

    if(num == 0) {
        P1 = 128 * mult - 512;
        P2 = num;
        P3 = denom;
    } else {
        P1 = (uint32_t)(128 * mult + floor(128 * ((float)num/ (float)denom)) - 512);
        P2 = (uint32_t)(128 * num - denom * floor(128 * ((float)num / (float)denom)));
        P3 = denom;
    }
    byte addr = (pll == SI5351_PLL_A) ? SI5351_PLLA_ADDR : SI5351_PLLB_ADDR;

    write(addr, (P3 & 0x0000FF00) >> 8);
    write(addr + 1, (P3 & 0x000000FF));
    write(addr + 2, (P1 & 0x00030000) >> 16);
    write(addr + 3, (P1 & 0x0000FF00) >> 8);
    write(addr + 4, (P1 & 0x000000FF));
    write(addr + 5, ((P3 & 0x000F0000) >> 12) | ((P2 & 0x000F0000) >> 16));
    write(addr + 6, (P2 & 0x0000FF00) >> 8);
    write(addr + 7, (P2 & 0x000000FF));
    
}

/*
 * Set up out clock frequencies
 * Code taken and slightly modified from adafruit si5351 library
 */

void setup_clock(plldev_t pll, byte port, uint32_t div, uint32_t num, uint32_t denom)
{
    if( port > 2 ) return;
    if( div < 4 || div > 2048 ) return;
    if( (denom == 0) || (denom > 0xFFFFF) ) return;
    if( num > 0xFFFFF) return;

    uint32_t P1, P2, P3;
    if (num == 0) {
        P1 = 128 * div - 512;
        P2 = 0;
        P3 = denom;
    } else if (denom == 1){
        P1 = 128 * div + 128 * num - 512;
        P2 = 128 * num - 128;
        P3 = 1;
    } else {
        P1 = (uint32_t)(128 * div + floor(128 * ((float)num/ (float)denom)) - 512);
        P2 = (uint32_t)(128 * num - denom * floor(128 * ((float)num / (float)denom)));
        P3 = denom;
    }
    byte addr = 0;
    switch(port) 
    {
        case SI5351_PORT0: 
            addr = SI5351_REGISTER_42_MULTISYNTH0_PARAMETERS_1;
            break;
        case SI5351_PORT1:
            addr = SI5351_REGISTER_50_MULTISYNTH1_PARAMETERS_1;
            break;
        case SI5351_PORT2:
            addr = SI5351_REGISTER_58_MULTISYNTH2_PARAMETERS_1;
            break;
    }

    byte buffer[8] = {
        (P3 & 0xFF00) >> 8,
        P3 & 0xFF,
        ((P1 & 0x30000) >> 16) | lastRdivValue[port],
        (P1 & 0xFF00) >> 8,
        P1 & 0xFF,
        ((P3 & 0xF0000) >> 12) | ((P2 & 0xF0000) >> 16),
        (P2 & 0xFF00) >> 8,
        P2 & 0xFF
    };

    write_bulk(addr, buffer, 8);

    byte clkCtrlReg = 0x0F;

    if( pll == SI5351_PLL_B )
        clkCtrlReg |= (1 << 5);

    if( num == 0 )
        clkCtrlReg |= (1 << 6);

    switch(port) 
    {
        case SI5351_PORT0: 
            write(SI5351_REGISTER_16_CLK0_CONTROL, clkCtrlReg);
            break;
        case SI5351_PORT1:
            write(SI5351_REGISTER_17_CLK1_CONTROL, clkCtrlReg);
            break;
        case SI5351_PORT2:
            write(SI5351_REGISTER_18_CLK2_CONTROL, clkCtrlReg);
            break;
    }
}

void reset_pll()
{
    write(SI5351_REGISTER_177_PLL_RESET, (1 << 7) | (1 << 5));
}
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

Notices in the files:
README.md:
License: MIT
